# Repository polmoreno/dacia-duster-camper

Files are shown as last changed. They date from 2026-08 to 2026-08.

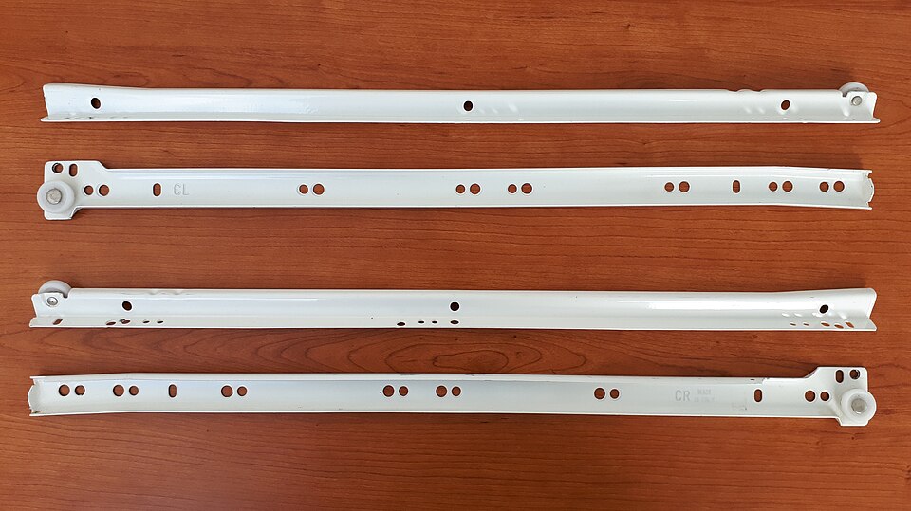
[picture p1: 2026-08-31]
docs/site/img/ref/drawer-slide.jpg

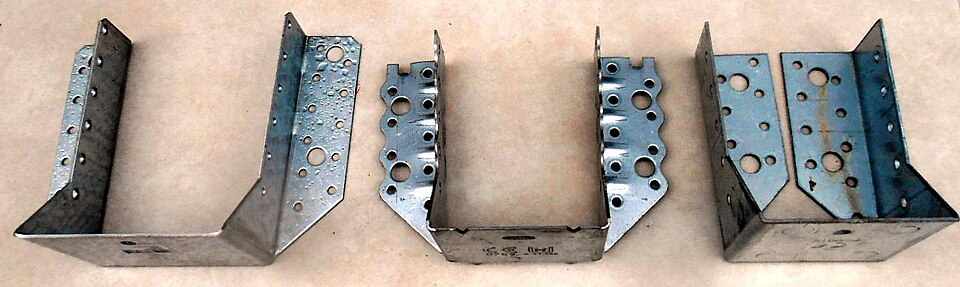
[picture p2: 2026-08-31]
docs/site/img/ref/joist-hanger.jpg

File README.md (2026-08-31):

# Duster II Sleep Pack clone

DIY plans for a **Dacia Duster II (2018–2024) 1.6 GLP 115 Ambiance 4x2** clone of the official InNature Sleep Pack.

The factory SKU ([7717274284](https://www.dacia.es/accesorios-dacia/catalogo/detalles.html?productId=PA_7717274284)) is a **Duster III** part. It will not drop into this car. The **sleep size** does: **1900 × 950 mm** between the wheel arches, **1300 mm** at the rear doors via slide-out wings.

3-in-1 only: removable boot box, storage while the bed is open, rear picnic table (15 kg). No kitchen. No drilling.

## Quick start

0. Open the workshop site (English / Catalan): [docs/site/](docs/site/index.html) — parts, tape-measure fit, shopping list, 3D, build steps.
1. Print and fill [docs/vehicle.md](docs/vehicle.md) in the car.
2. If your numbers differ from v0.1, edit [cad/params.py](cad/params.py) and run `python cad/export_cnc.py`.
3. Plot [cad/export/cardboard-templates.svg](cad/export/cardboard-templates.svg) at 100% and tape it in the Duster.
4. Cut two 2440 × 1220 × 15 mm sheets from [cad/export/sheet-1.svg](cad/export/sheet-1.svg) / [sheet-2.svg](cad/export/sheet-2.svg) (DXF next to them).
5. Build and deploy with [docs/build-guide.md](docs/build-guide.md). Hardware: [hardware/bom.md](hardware/bom.md).
6. Watch the 3D assemble / fold / sleep animation in [docs/viewer/](docs/viewer/index.html).

## Repo map

| Path | What |
| --- | --- |
| [docs/site/](docs/site/index.html) | Interactive workshop site (EN / CA) for the hardware-store counter |
| [docs/research.md](docs/research.md) | Official pack vs Duster II, sources, why 190×130 is still the target |
| [docs/vehicle.md](docs/vehicle.md) | Published dims + tape-measure checklist (including 130 cm wings) |
| [docs/build-guide.md](docs/build-guide.md) | Cut, assemble, strap, official 9-step unfold, safety |
| [docs/drawings/](docs/drawings/) | Folded, unfolded, exploded SVG |
| [docs/viewer/](docs/viewer/index.html) | 3D animation: kit → folded box → picnic / sleep |
| [cad/params.py](cad/params.py) | All millimetre variables |
| [cad/sleep_pack.scad](cad/sleep_pack.scad) | OpenSCAD preview (`unfolded = true`) |
| [cad/export/](cad/export/) | Nested SVG + DXF, cut list, cardboard templates |
| [hardware/bom.md](hardware/bom.md) | Wood, hinges, straps, foam |

## v0.1 numbers (change after measuring)

| | mm |
| --- | --- |
| Box outer | 950 × 800 × 320 |
| Bed | 1900 × 950 |
| Wings | 175 each → **1300** at the doors |
| Plywood | 15 mm, 2 sheets, 4.23 m² net |

Typical DIY cost **€200–380** vs ~€1,590 official.

Python 3.10+ is enough to regenerate files (`python cad/export_cnc.py`). No extra packages.

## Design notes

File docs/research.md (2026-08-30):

# Research: Duster II Sleep Pack clone

Original design notes. This project clones the **public function** of Dacia’s InNature Sleep Pack for a **Duster II (2018–2024) 1.6 GLP 115 Ambiance 4x2**. It does not copy official CNC outlines or paid DIY PDFs.

## Official SKU vs this car

| Item | Official pack | This project |
| --- | --- | --- |
| SKU | [7717274284](https://www.dacia.es/accesorios-dacia/catalogo/detalles.html?productId=PA_7717274284) (Spain) | Original Duster II geometry |
| Title on dacia.es | Pack Sleep for Duster 4x2 and **Hybrid 150 4x4 without spare** | — |
| Fitment | Duster III (2024+), plus separate SKUs for Jogger / Bigster | Duster II 4x2 GLP |
| Box width | Built for **1000 mm** between wheel arches | Built for **977 mm** (target outer width 950 mm) |
| Sleep size | 190 × 130 cm mattress (100 cm in the boot, 130 cm at the rear doors) | Same sleep size, Duster II envelope |
| Weight | ~45 kg box + 5 kg mattress | Target ≤ 45 kg box |
| Price | ~€1,590–1,650 | DIY wood + hardware ~€200–400 |
| Designer | Eric Bouffette / Qstomize (Renault Group) | This repo |

Hybrid 150 4x4 exists only on Duster III. The 1.6 SCe 115 LPG (GLP) and Ambiance trim are Duster II. Dacia NL states each model has its **own** Sleep Pack because the interiors differ.

The dacia.es “modelos disponibles” list that includes Sandero, Logan, Dokker, Lodgy, Spring, and “DUSTER 1 PHAS2” is a catalogue dump, not a fitment check. It does not list Duster II.

**The official box will not drop into a Duster II boot.** The official *sleep size* is still the target.

### Published cargo comparison

| Dimension | Duster III (official pack car) | Duster II 4x2 (this car) |
| --- | --- | --- |
| Width between wheel arches | 1000 mm | **977 mm** |
| Load length, seats up | ~665–990 mm (generation-specific) | **990 mm** |
| Load length, seats folded | 1672 mm | **1792 mm** (longer) |
| Rear elbow / shoulder | ~1433 / 1377 mm | **1416 / 1379 mm** |
| Boot volume 4x2 | ~472 L | **445 L** |
| Spare / LPG | Hybrid / no-spare variants | LPG tank in the spare-wheel well, typically no spare |

Sources: Duster II press kit ([RE37517](https://www.press.dacia.co.uk/assets/documents/original/3064-RE37517DaciaDusterPressKitV1.pdf)); Duster III dimensions (Autotijd / Dacia).

The official 190 × 130 cm figure is the **unfolded mattress**, not the box. Motorpasión quotes the Duster III box at about **1000 × 800 × 300 mm**. Reviews (Motor1) give the bed as **190 cm long, 100 cm in the boot, 130 cm at the rear doors**.

## Official unfold (public reviews)

Compiled from Autofácil, Auto Express, and Motor1. No official exploded drawing is public.

1. Push the front seats fully forward (cushion and backrest).
2. Fold the rear seats.
3. Remove the two wooden cross-slats stored on the box (used later).
4. Release the retaining strap and pull the **concertina / hinged frame** out over the folded seatbacks.
5. Slot the two cross-slats across the frame (width-ways braces).
6. Unfold the **Z-fold three-section deck** so it rests on the box and the frame.
7. Slide out the **side wings** to use the space up to the rear door glass (~130 cm at the shoulders).
8. Unfold the foam mattress (stored between the parcel shelf and the box) and add the two wing pads.
9. Add side / footwell cushions so nobody rolls into the front footwell.

Other official traits used here:

- Rear flap of the box folds down as a picnic table (**15 kg max**; do not sit on it).
- Storage stays reachable with the bed open (~160–175 L on Duster III; this clone targets a similar cavity).
- Box straps to factory boot tie-downs. No drilling.
- Mattress: 100% polyester foam, **32 kg/m³** (Motor1).
- Two-adult rating on aftermarket listings: **180 kg** total.

Early prototypes used fold-out flaps for the extra width; the production pack uses **slide-out** wings (Auto Express).

## Commercial and DIY sources (not copied)

None of these publish free complete cut lists for a Sleep Pack clone. Geometry in this repo is original.

| Source | What it is | Sleep size | Notes |
| --- | --- | --- | --- |
| [Kit Mueble Camper](https://www.kitmueblecamper.com/dacia-duster/) | Paid furniture kit, kitchen + chest | ~180 × 110 cm | 15 mm plywood, ~30–35 kg poplar, from ~€600. 2017–2023 is workshop adaptation. |
| [Simple Campervans MK2](https://www.simplecampervans.com/shop/conversion-modules/dacia-duster-camper-van-conversion/) | Paid CNC module | 1730 × 900 mm (cushions 1800 × 1000) | 12 mm birch, 21 kg, £399. No kitchen. |
| [Campal Estate](https://campal.co.uk/campal-estate/) | Paid kitchen + bed kit | Vehicle-specific | £1,320–1,520. Separate small/extendable variant for Duster 4x4 / bi-fuel / spare. |
| [Tchao Tchao](https://tchao-tchao.com/es/pages/kit-amenagement-duster) | Paid Duster kit | 190 × 122 cm | Two drawers, adjustable legs. |
| [mobiles-bett.de](https://mobiles-bett.de/en/dacia-duster-en/) | Paid €9.95 instructions | 1950 × 1100 mm | Square timber + fibreboard platform, not a 3-in-1 box. |
| [Etsy camping-box PDF](https://www.etsy.com/listing/1596598387/wooden-camping-box-project-foldable-bed) | Paid tutorial | 164 × 98 cm deck | Written for Duster II 1.0 TCe LPG 4x2 Access. |
| [Reddit Duster 2 bed](https://www.reddit.com/r/Dacia/comments/1sq65s0/diy_bed_frame_for_the_duster_2/) | Photos | — | No published plans. |
| [Foro Dacia kit thread](https://www.foroclub.es/duster/viewtopic.php?t=6945) | Forum | — | Author promised plans; they were not posted. |
| [Nimblecamper DIY](https://nimblecamper.com/dacia-duster-camper-diy/) | Photo example | ~176 cm boot, 180+ cm with front seats forward | Push front seats forward for length. |

Third-party Duster II kits usually skip the official **wings**, which is why they advertise ~180 × 110 cm. This clone keeps the wings so the sleep surface matches the official 190 × 100 / 130 cm.

## Design decisions

1. **Sleep size matches the official pack:** 1900 mm long, 1000 mm between the arches, 1300 mm at the rear doors via slide-out wings.
2. **Box is narrower than the official pack:** 950 mm outer width (977 mm arches minus clearance).
3. **No kitchen drawer.** 3-in-1 only: storage + table + bed.
4. **Parametric CAD.** Published Duster II numbers are v0.1. Measure the car, then regenerate cuts (see [vehicle.md](vehicle.md)).
5. **15 mm birch or phenolic plywood.** Official pack is hygienic birch. Butt joints, glue, screws, corner brackets — no hidden dados required.
6. **Quita-y-pon.** Strapped cargo, not a homologated conversion.

## Sources

- [dacia.es SKU 7717274284](https://www.dacia.es/accesorios-dacia/catalogo/detalles.html?productId=PA_7717274284)
- [dacia.co.uk InNature](https://www.dacia.co.uk/innature-accessories.html)
- [dacia.nl Sleep Pack (per-model sizes)](https://www.dacia.nl/accessoires/sleep-pack.html)
- [Autofácil: nine-step Jogger/Duster unfold](https://www.autofacil.es/video-dacia-pack-sleep/)
- [Auto Express: prototype, slats, wings](https://www.autoexpress.co.uk/dacia/359729/dacia-jogger-sleep-pack-exclusive-review-night-amazing-budget-motorhome)
- [Motor1 Duster Sleep Pack test (190 / 100 / 130, 45+5 kg, 32 kg/m³)](https://www.motor1.com/reviews/723549/dacia-duster-sleep-pack-first-drive-review/)
- [Autocar Duster overnight](https://www.autocar.co.uk/car-news/features/future-camping-we-spend-night-dacias-%C2%A32000-sleep-pack)
- [Motorpasión box envelope ~1000 × 800 × 300 mm](https://www.motorpasion.com/furgonetas-y-caravanas/me-he-configurado-dacia-duster-sea-camper-24-000-euros-ahora-tengo-coche-casa-ruedas-para-finde)
- [Autobild: Duster III only](https://www.autobild.es/motor/dacia-duster-puede-convertirse-camper-con-dacia-pack-sleep-una-caja-con-que-se-puede-hacer-magia_6929495_0.html)

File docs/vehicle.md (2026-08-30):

# Duster II 4x2 GLP — vehicle pack and measure checklist

Print this page. Fill the **Measured** column in millimetres before cutting 15 mm plywood.

Car: **Dacia Duster II (2018–2024) 1.6 GLP 115 Ambiance 4x2**

GLP (LPG) tanks sit in the spare-wheel well. Expect a repair kit, not a spare, and a relatively flat boot floor compared with a 4x4 that carries a spare.

## Published starting dimensions (v0.1 CAD)

From the Duster II press kit unless noted. These are the defaults in `cad/params.py`.

| ID | What | Published | v0.1 CAD | Measured |
| --- | --- | --- | --- | --- |
| A | Width between wheel arches (narrowest) | 977 mm | box outer **950 mm** | |
| B | Load length, rear seats **up**, floor to seatback | 990 mm | box depth **800 mm** | |
| C | Load length, rear seats **folded**, floor to front-seat back | 1792 mm | bed length **1900 mm** (front seats fully forward) | |
| D | Rear elbow width | 1416 mm | — | |
| E | Rear shoulder width | 1379 mm | wings to **1300 mm** | |
| F | Boot volume 4x2 | 445 L | — | |
| G | Parcel-shelf height above boot floor | not published | box height **320 mm** | |
| H | Wheelbase | 2674 mm | — | |

Duster III (official pack car) is **1000 mm** between arches and **1672 mm** seats-folded. Do not use those numbers for cuts.

## How to measure

Use a steel tape. Two people helps for C and W1. Record the **smallest** number if the gap tapers.

Set-up for sleep-mode measurements (C, G, S1–S3, W1–W3, L1):

1. Front seats fully forward, backrests upright or slightly reclined as you would sleep.
2. Rear headrests removed or pushed down.
3. Rear seatbacks folded toward the front.
4. Parcel shelf removed.

Set-up for daily-mode measurements (A, B, G, T1–T4):

1. Rear seats up, usable for passengers.
2. Parcel shelf in its normal position.

## Print-ready checklist

### Boot envelope (box must fit)

| ID | Measure | How | Target / limit | Measured mm | OK? |
| --- | --- | --- | --- | --- | --- |
| A | Arch width | Narrowest gap between wheel-arch plastics, 50 mm above the floor | ≥ 960 (950 box + 10 clearance) | | |
| A2 | Arch width at 200 mm | Same gap at 200 mm above the floor (arches often lean in) | ≥ 960 | | |
| A3 | Arch width at shelf | Same gap at parcel-shelf height | ≥ 960 | | |
| B | Depth seats up | Inner tailgate plastic to rear seatback, on the floor centreline | ≥ 820 (800 box + 20) | | |
| B2 | Depth at mid height | Same, at 160 mm above the floor | ≥ 820 | | |
| G | Shelf height | Boot floor to underside of parcel shelf, centre | ≥ 330 (320 box + 10) | | |
| G2 | Floor flatness | Highest bump vs lowest point of the boot floor (GLP well / foam floor) | note mm | | |
| T1–T4 | Tie-downs | X/Y of each factory loop from the left-front corner of the boot floor | strap reach | | |

### Sleep envelope (bed 190 × 100 / 130)

| ID | Measure | How | Target / limit | Measured mm | OK? |
| --- | --- | --- | --- | --- | --- |
| C | Length seats folded | Inner tailgate to the back of the front seats (seats fully forward) | ≥ 1900 | | |
| C2 | Length to dash / pedals | If C < 1900, can feet go between the front seats? Note extra mm | 1900 − C | | |
| L1 | Deck height check | Folded seatback height above boot floor (highest point of the 60/40 split) | compare to 320 | | |
| S1 | Seatback angle | Angle of the folded backrest from horizontal (phone inclinometer) | typical 10–25° | | |
| S2 | Seatback contact Y | Distance from inner tailgate to the first point the frame will rest on the seatback | | | |
| S3 | Front footwell drop | Floor height in the rear footwell vs boot floor (for front legs) | | | |
| W1 | Door-area width | Inside-to-inside at **mattress height** (~320 mm) between rear door cards / plastics, with doors closed | ≥ 1320 (1300 + 20) | | |
| W2 | Door-area width at head | Same, 200 mm above the deck (shoulder room) | ≥ 1320 | | |
| W3 | Wing length available | Along Y, how long a 150 mm-wide wing can sit without hitting the C-pillar or arch | ≥ 600 | | |

### Hardware

| ID | Measure | How | Measured |
| --- | --- | --- | --- |
| H1 | Tie-down type | Photo + loop ID size (mm) | |
| H2 | 60/40 split | Both sides fold? Height mismatch left vs right (mm) | |
| H3 | Parcel shelf keep? | Can the shelf sit above a 320 mm box? yes/no | |
| H4 | Year / VIN year | Plate or V5 | |

## Sketch — where to put the tape

```text
TOP VIEW (rear seats folded, looking down)

        FRONT SEATS (pushed forward)
   +----------- C / C2 ----------------+
   |                                   |
   |     W1 / W2 (door-area width)     |
   |   <-------- 1300 target --------> |
   |         [wing]     [wing]         |
   |                                   |
   |  A = arch width (977 published)   |
   |   <-------- 950 box -------->     |
   |                                   |
 TAILGATE                         TAILGATE
   +------------- B (seats up) --------+

SIDE VIEW

  roof
   |        parcel shelf ---- G
   |   +--------+
   |   |  BOX   | 320          folded seatback / S1
   |   | 800 mm |==============\\======== deck 1900
   |   +--------+              legs
   +---- boot floor / G2 --+  footwell S3
         T1  T2     T3  T4
```

## After measuring

1. Edit the matching variables in [`cad/params.py`](../cad/params.py) (`BOOT_ARCH_WIDTH`, `BOX_WIDTH`, `BOX_DEPTH`, `BOX_HEIGHT`, `BED_LENGTH`, `WING_EXTRA`, `SEATBACK_ANGLE_DEG`, …).
2. Run `python cad/export_cnc.py` to regenerate SVG, DXF, nests, and drawings.
3. Cut the **cardboard templates** first ([`cad/export/cardboard-templates.svg`](../cad/export/cardboard-templates.svg)). Tape them in the car.
4. Only then cut 15 mm plywood.

If A, A2, or A3 is under 960 mm, shrink `BOX_WIDTH` to measured − 20 mm. If W1 is under 1320 mm, shrink `WING_EXTRA` so `BED_WIDTH + 2*WING_EXTRA` ≤ W1 − 20. If C is under 1900 mm, either accept a shorter bed or plan to put feet between the front seats and shorten `BED_LENGTH` to what actually lies flat.

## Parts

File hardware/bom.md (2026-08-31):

# Bill of materials — Duster II Sleep Pack clone v0.1

Prices are Spain hardware-store ballparks. Preferred shop: **[Cadena 88](https://www.cadena88.com/es)** (pick a store by postcode; web prices are recommended PVP, stock is local). Buy after the cardboard templates fit.

Cadena 88 web matches (Aug 2026):

| Need | Cadena 88 product | Link |
| --- | --- | --- |
| Edge band 22 mm | Canto melamina EHL 5 m × 22 mm, SKU 111D2283 (~4,60 €) | [producte](https://www.cadena88.com/es/ferreteria/ferreteria-para-muebles/cantos-para-tablero/canto-melamina-ehl-5-m-x-22-mm) |
| Piano hinge | Bisagra piano niquelada EHL 32 × 1020 mm, SKU 111D383 (~4,10 €) | [producte](https://www.cadena88.com/es/cerrajeria/accesorios-puertas-y-ventanas/bisagras-y-pernios/bisagras-de-piano/bisagra-piano-niquelada-ehl-en-tiras) |
| Leg hinges | Bisagra EHL 207, pack de 4, 40 × 35 mm, SKU 111D315 (~4,40 €) | [producte](https://www.cadena88.com/es/cerrajeria/accesorios-puertas-y-ventanas/bisagras-y-pernios/bisagras/bisagra-ehl-modelo-207) |
| Table bolts | Pasador cerrojo EHL bicromatado 70 mm, SKU 111D313 (~4,15 €) | [producte](https://www.cadena88.com/es/cerrajeria/pasadores-candados-y-cierrapuertas/pasadores-y-pestillos-para-puertas/pasadores-y-pestillos/pasador-cerrojo-ehl-bicromatado) |
| Wing runners | Guía metálica EUROLATON **500 mm** (~4,50 € / pair, 45 kg) | [producte](https://www.cadena88.com/es/ferreteria/ferreteria-para-muebles/complementos-para-muebles/guia-metalica-eurolaton-cajones) |
| Corner brackets | Escuadras EHL punta redonda 40 × 40 mm, SKU 111D12-26 (from ~2,00 €) | [producte](https://www.cadena88.com/es/ferreteria/ferreteria-para-muebles/pletinas-y-escuadras-de-ensamblaje/escuadras-ehl-punta-redonda-bricomatadas) |
| Glue | Cola blanca rápida CEYS 500 g, SKU 4572B59 (~6,60 €) | [producte](https://www.cadena88.com/es/fijaciones-y-adhesivos/adhesivos-colas-y-cintas/colas-blancas/adhesivo-cola-blanca-rapida-ceys-500-gr) |
| Screws | SPAX CP Wirox chipboard — pick 4×40 and 3.5×20 on the same page | [producte](https://www.cadena88.com/es/fijaciones-y-adhesivos/tornillos-tacos-y-clavos/tornillos-y-tirafondos/tornillos-rosca-madera/tornillo-aglomerado-spax-cp-wirox-z2-tr) |

**Ask at the shop (not on the website):** 15 mm birch/phenolic 2440 × 1220, pine 20×20 cleat, felt pads, table stays, cam-buckle straps, foam mattress. Do not buy the Emuca 30 mm table tops.

## Plywood

| Item | Spec | Qty | Notes | Est. € |
| --- | --- | --- | --- | --- |
| Birch or phenolic plywood | 2440 × 1220 × **15 mm** | **2 sheets** | Nested in [`cad/export/sheet-1.svg`](../cad/export/sheet-1.svg) and `sheet-2`. Poplar is lighter; HPL phenolic is toughest. | 80–140 |
| Edge banding | 22 mm iron-on, matching | 20 m | All cut edges that you will touch | 10 |
| Felt / wool pads | 3 mm, self-adhesive | 1 pack | Under the box and on seat-rest blocks | 6 |

Cut list: [`cad/export/cutlist.csv`](../cad/export/cutlist.csv) and [`cad/export/parts.md`](../cad/export/parts.md). Net area 4.23 m²; two sheets are 5.95 m².

Optional instead of plywood slat sockets: four steel 40 × 40 × 80 mm U-brackets.  
Optional instead of plywood `WING_RUNNER` strips: two pairs of 550 mm drawer slides under P2.

## Timber (not CNC)

| Item | Spec | Qty | Use | Est. € |
| --- | --- | --- | --- | --- |
| Pine cleat | 20 × 20 mm | 3 m | Bottom sits on cleats glued to SIDE_L/R, FRONT, RAIL_BOT | 6 |

## Hinges and stays

| Item | Spec | Qty | Use | Est. € |
| --- | --- | --- | --- | --- |
| Piano hinge | 32 × 950 mm, steel or stainless | 2 | DECK_P1–P2 and P2–P3 | 16 |
| Piano hinge | 32 × 920 mm | 2 | TABLE to RAIL_TOP; P1 to RAIL_TOP | 16 |
| Piano hinge | 32 × 80 mm (or 2× 40 mm butt) | 4 | RAIL_SEG A–B (two per side) | 8 |
| Butt hinge | 40 mm | 4 | LEG to RAIL_SEG B (two per leg) | 4 |
| Folding table stay | 200–250 mm, 15 kg rated | 2 | TABLE underside to SIDE_L/R | 10 |
| Barrel bolts | 50 mm | 2 | Hold TABLE closed while driving | 4 |

## Fasteners

| Item | Spec | Qty | Use | Est. € |
| --- | --- | --- | --- | --- |
| Wood screws | 4 × 40 mm | 100 | Box carcass | 6 |
| Wood screws | 3.5 × 20 mm | 80 | Hinges, runners, sockets | 4 |
| Corner brackets | 40 × 40 × 40 mm | 8 | Inside box corners | 6 |
| PVA / PU wood glue | D3/D4 | 1 bottle | All butt joints | 8 |
| Threaded inserts + M6 | optional | 8 | If you want a take-apart box | 8 |

## Straps and comfort

| Item | Spec | Qty | Use | Est. € |
| --- | --- | --- | --- | --- |
| Cam-buckle lashing strap | 25 mm × 2 m | 4 | Through SIDE slots to factory tie-downs | 16 |
| Soft loop / webbing | 25 mm | 2 m | Protect the tie-down plastics | 4 |
| Foam mattress | 50 mm, 32 kg/m³ polyester (official spec) or 80 mm PU | 1 | 950 × 1900 mm main | 40–80 |
| Wing pads | same foam | 2 | 175 × 549 mm | included if cut from leftover |
| Footwell pads | 80 mm foam | 2 | 150 × 400 mm | 15 |
| Mattress covers | zip, washable | 3 | Main + two wings | 20 |

80 mm foam is more comfortable than the official 50 mm / 32 kg/m³ slab. If you use 80 mm, confirm parcel-shelf height (measure G) still clears the folded stack.

## Tools

Circular saw or CNC/panel saw, 2 mm drill, countersink, square, clamps, iron (edge band), 2 mm hex / Pozidriv. A hardware store will cut the nest if you take printed [`sheet-1.svg`](../cad/export/sheet-1.svg) / [`sheet-2.svg`](../cad/export/sheet-2.svg) or the DXF files.

## Total

| | € |
| --- | --- |
| Wood + glue + band | 100–160 |
| Hardware | 70–100 |
| Foam + covers | 75–120 |
| **Typical DIY** | **€200–380** |

Official Sleep Pack: ~€1,590. Kit Mueble Camper (different layout): from ~€600.

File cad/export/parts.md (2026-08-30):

# CNC parts — v0.1

Plywood area (no waste): **4.23 m²**.
Sheets: **2440 × 1220 × 15 mm**.

| Part | Qty | W mm | H mm | Group | Notes |
| --- | --- | --- | --- | --- | --- |
| `SIDE_L` | 1 | 800 | 320 | box | Left side. Four strap slots to factory tie-downs. |
| `SIDE_R` | 1 | 800 | 320 | box | Right side. Same as SIDE_L (box is symmetric). |
| `BOTTOM` | 1 | 920 | 770 | box | Sits between the sides. Glue and screw into 20x20 cleats. |
| `FRONT` | 1 | 920 | 305 | box | Cabin-facing wall. Top edge is the landing for deck P1. |
| `RAIL_TOP` | 1 | 920 | 70 | box | Tailgate-end top rail. Piano hinge for TABLE and for P1. |
| `RAIL_BOT` | 1 | 920 | 50 | box | Tailgate-end bottom rail. Closes the storage opening. |
| `TABLE` | 1 | 918 | 198 | box | Picnic flap, 15 kg max. Finger slot. Two folding stays. |
| `DECK_P1` | 1 | 950 | 800 | deck | Box lid / first deck section. Hinge to RAIL_TOP. |
| `DECK_P2` | 1 | 950 | 549 | deck | Middle section (rear-door bay). Wing tracks on the underside. |
| `DECK_P3` | 1 | 950 | 549 | deck | Front section (toward the front seats). |
| `WING` | 2 | 175 | 549 | deck | Slide-out shoulder wings. One left, one right, under P2. |
| `WING_RUNNER` | 4 | 549 | 20 | deck | Pair of 20 mm guides per wing, screwed under P2. |
| `RAIL_SEG` | 4 | 550 | 80 | frame | Two hinged segments per side. Piano hinge between A/B. |
| `SLAT` | 2 | 918 | 80 | frame | Width-ways braces. Drop into U-sockets on the rails. |
| `LEG` | 2 | 80 | 305 | frame | Folding front legs. Hinge to the free end of RAIL_SEG B. |
| `SEAT_REST` | 2 | 80 | 50 | frame | Short blocks under the rails where they meet the seatbacks. |
| `SLAT_SOCKET` | 4 | 40 | 90 | frame | U-shaped catch. Screw to the inside of the rails. Or use steel U-brackets. |

## Locked parameters

| Name | mm |
| --- | --- |
| `BOX_WIDTH` | 950 |
| `BOX_DEPTH` | 800 |
| `BOX_HEIGHT` | 320 |
| `INNER_W` | 920 |
| `INNER_D` | 770 |
| `INNER_H` | 305 |
| `BED_LENGTH` | 1900 |
| `BED_WIDTH` | 950 |
| `WING_TOTAL` | 1300 |
| `WING_EXTRA` | 175 |
| `P1_LEN` | 800 |
| `P2_LEN` | 549 |
| `P3_LEN` | 549 |
| `FRAME_LEN` | 1100 |
| `TABLE_W` | 918 |
| `TABLE_H` | 198 |
| `PLY` | 15 |

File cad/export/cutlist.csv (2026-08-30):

name | qty | width_mm | height_mm | thickness_mm | group | notes
SIDE_L | 1 | 800.0 | 320.0 | 15 | box | Left side. Four strap slots to factory tie-downs.
SIDE_R | 1 | 800.0 | 320.0 | 15 | box | Right side. Same as SIDE_L (box is symmetric).
BOTTOM | 1 | 920.0 | 770.0 | 15 | box | Sits between the sides. Glue and screw into 20x20 cleats.
FRONT | 1 | 920.0 | 305.0 | 15 | box | Cabin-facing wall. Top edge is the landing for deck P1.
RAIL_TOP | 1 | 920.0 | 70.0 | 15 | box | Tailgate-end top rail. Piano hinge for TABLE and for P1.
RAIL_BOT | 1 | 920.0 | 50.0 | 15 | box | Tailgate-end bottom rail. Closes the storage opening.
TABLE | 1 | 918.0 | 198.0 | 15 | box | Picnic flap; 15 kg max. Finger slot. Two folding stays.
DECK_P1 | 1 | 950.0 | 800.0 | 15 | deck | Box lid / first deck section. Hinge to RAIL_TOP.
DECK_P2 | 1 | 950.0 | 549.0 | 15 | deck | Middle section (rear-door bay). Wing tracks on the underside.
DECK_P3 | 1 | 950.0 | 549.0 | 15 | deck | Front section (toward the front seats).
WING | 2 | 175.0 | 549.0 | 15 | deck | Slide-out shoulder wings. One left; one right; under P2.
WING_RUNNER | 4 | 549.0 | 20.0 | 15 | deck | Pair of 20 mm guides per wing; screwed under P2.
RAIL_SEG | 4 | 550.0 | 80.0 | 15 | frame | Two hinged segments per side. Piano hinge between A/B.
SLAT | 2 | 918.0 | 80.0 | 15 | frame | Width-ways braces. Drop into U-sockets on the rails.
LEG | 2 | 80.0 | 305.0 | 15 | frame | Folding front legs. Hinge to the free end of RAIL_SEG B.
SEAT_REST | 2 | 80.0 | 50.0 | 15 | frame | Short blocks under the rails where they meet the seatbacks.
SLAT_SOCKET | 4 | 40.0 | 90.0 | 15 | frame | U-shaped catch. Screw to the inside of the rails. Or use steel U-brackets.

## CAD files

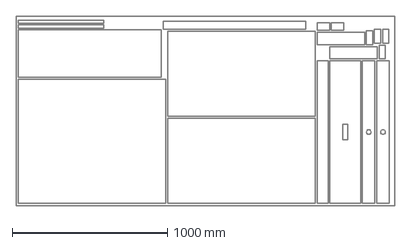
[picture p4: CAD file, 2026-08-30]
cad/export/sheet-1.dxf
2440.0 x 1220.0 mm

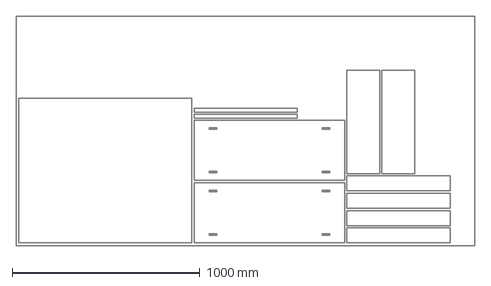
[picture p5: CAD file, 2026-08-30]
cad/export/sheet-2.dxf
2440.0 x 1220.0 mm

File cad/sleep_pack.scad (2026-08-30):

// Duster II Sleep Pack clone — v0.1 visualization
// Open in OpenSCAD. Set unfolded = true to see the bed deployed.
// Numbers match cad/params.py — if you change params.py, update these.

unfolded = false;

ply = 15;
box_w = 950;
box_d = 800;
box_h = 320;
inner_w = box_w - 2 * ply;
inner_d = box_d - 2 * ply;
inner_h = box_h - ply;
rail_top_h = 70;
rail_bot_h = 50;
table_w = inner_w - 2;
table_h = box_h - rail_top_h - rail_bot_h - 2;

p1 = 800;
p2 = 549;
p3 = 549;
deck_gap = 2;
bed_w = 950;
wing = 175;
wing_len = p2;
frame_rail_h = 80;
leg_h = inner_h;

module ply_xy(w, d) {
    cube([w, d, ply]);
}

module box() {
    // sides
    cube([ply, box_d, box_h]);
    translate([box_w - ply, 0, 0]) cube([ply, box_d, box_h]);
    // bottom
    translate([ply, ply, 0]) cube([inner_w, inner_d, ply]);
    // front (cabin)
    translate([ply, box_d - ply, ply]) cube([inner_w, ply, inner_h]);
    // rear rails
    translate([ply, 0, box_h - rail_top_h]) cube([inner_w, ply, rail_top_h]);
    translate([ply, 0, 0]) cube([inner_w, ply, rail_bot_h]);
}

module table_flap() {
    color("#c9b48a")
    translate([ply + 1, -table_h, rail_bot_h + 1])
        cube([table_w, ply, table_h]);
}

module deck_folded() {
    color("#c9b48a") {
        translate([0, 0, box_h]) ply_xy(bed_w, p1);
        translate([0, 0, box_h + ply]) ply_xy(bed_w, p2);
        translate([0, 0, box_h + 2 * ply]) ply_xy(bed_w, p3);
    }
}

module deck_open() {
    color("#c9b48a") {
        translate([0, 0, box_h]) ply_xy(bed_w, p1);
        translate([0, p1 + deck_gap, box_h]) ply_xy(bed_w, p2);
        translate([0, p1 + p2 + 2 * deck_gap, box_h]) ply_xy(bed_w, p3);
    }
    color("#b9d4c0") {
        translate([-wing, p1 + deck_gap, box_h]) ply_xy(wing, wing_len);
        translate([bed_w, p1 + deck_gap, box_h]) ply_xy(wing, wing_len);
    }
}

module frame_open() {
    color("#9aa7b5") {
        translate([ply, box_d, box_h - frame_rail_h])
            cube([ply, p2 + p3, frame_rail_h]);
        translate([box_w - 2 * ply, box_d, box_h - frame_rail_h])
            cube([ply, p2 + p3, frame_rail_h]);
        translate([2 * ply, box_d + 180, box_h - frame_rail_h])
            cube([inner_w - 2 * ply, ply, frame_rail_h]);
        translate([2 * ply, box_d + 180 + 400, box_h - frame_rail_h])
            cube([inner_w - 2 * ply, ply, frame_rail_h]);
        translate([ply, box_d + p2 + p3 - ply, 0])
            cube([ply, ply, leg_h]);
        translate([box_w - 2 * ply, box_d + p2 + p3 - ply, 0])
            cube([ply, ply, leg_h]);
    }
}

box();
if (unfolded) {
    table_flap();
    deck_open();
    frame_open();
} else {
    deck_folded();
}

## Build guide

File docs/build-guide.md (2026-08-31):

# Build and deploy guide — Duster II Sleep Pack clone v0.1

Official-style 3-in-1: boot box + picnic table + 1900 × 950 / 1300 mm winged bed. No kitchen. No drilling the car.

Read [research.md](research.md) and fill [vehicle.md](vehicle.md) before you cut 15 mm sheets.

## Safety

- Strap the box to the **factory boot tie-downs** whenever the car moves. Treat it as cargo (quita-y-pon), not a homologated conversion.
- Picnic table: **15 kg max**. Do not sit on it.
- Sleep load: **180 kg** total (two adults), same as aftermarket listings of the official pack.
- Deck must rest on the box, the two slats, and the front legs. Do not sleep on an unbraced Z-fold.
- Cook outside the car if you bring a stove. This kit has no kitchen. The car is GLP — keep cartridges disconnected in transit.
- Two people to lift the finished box (~30–45 kg).
- Do not block the rear-view if the folded stack sits above the parcel shelf. Measure G.

## 0. Measure, then cardboard

1. Fill the checklist in [vehicle.md](vehicle.md).
2. If any measured limit is tighter than v0.1, edit [`cad/params.py`](../cad/params.py) and run:

   ```text
   python cad/export_cnc.py
   ```

3. Plot [`cad/export/cardboard-templates.svg`](../cad/export/cardboard-templates.svg) at **100%** (1 unit = 1 mm), or grid it onto taped cardboard.
4. Tape the **box footprint** in the boot with the rear seats **up**. It must clear both arches.
5. Fold the rear seats, push the front seats forward, tape the **bed plan** and the **1300 mm width bar** at mattress height in the rear-door opening.
6. Only then cut plywood.

## 1. Cut

- Nest: [`cad/export/sheet-1.svg`](../cad/export/sheet-1.svg) + [`sheet-2.svg`](../cad/export/sheet-2.svg) (also DXF).
- Two 2440 × 1220 × 15 mm sheets.
- Black lines are cuts. Inner rectangles/circles are cut-outs (strap slots, table handle, slat finger holes).
- Label every part on the face that will be hidden.
- Edge-band every edge you will touch.
- Sand strap slots so webbing does not fray.

Part list: [`cad/export/parts.md`](../cad/export/parts.md).

## 2. Box carcass

Orientation: **Y = 0 at the tailgate**, **Y = 800 at the cabin wall**.

1. Glue 20 × 20 cleats on SIDE_L, SIDE_R, FRONT, and RAIL_BOT, 15 mm up from the bottom so BOTTOM sits flush with the lower edge of the sides.
2. Stand SIDE_L and SIDE_R. Screw FRONT between them at the cabin end, sitting on BOTTOM (or on the cabin cleat). `FRONT` is 305 mm tall so its top lands flush with the 320 mm sides and becomes a landing for DECK_P1.
3. Screw RAIL_BOT and RAIL_TOP between the sides at the tailgate. RAIL_TOP’s top is flush with the side tops.
4. Drop in BOTTOM. Glue and screw down into the cleats.
5. Add four 40 mm corner brackets inside.
6. Piano-hinge TABLE to the **lower** edge of RAIL_TOP so the flap hangs as the rear wall, then folds **out** to horizontal. Fit two folding stays to the sides. 15 kg max.
7. Fit two barrel bolts so TABLE cannot drop while driving.
8. Stick felt under the box.

Storage is the inner cavity (920 × 770 × ~290 mm), reachable through the table opening with the bed open.

## 3. Concertina frame

1. Piano-hinge two RAIL_SEG pieces end-to-end (550 + 550 = 1100 mm) for the left rail. Repeat for the right.
2. Screw two SLAT_SOCKET catches on the inside of each assembled rail — one at ~180 mm from the box, one at ~580 mm. Opening faces up so a SLAT drops in.
3. Butt-hinge one LEG to the free end of each rail so the leg folds against the rail for storage.
4. Screw a SEAT_REST block under each rail where it will sit on the folded seatbacks (measure S2). Add felt.
5. Hinge the **box end** of each rail to the inside of FRONT, near the top, so the rails fold **into** the box for driving and pull out over the seats for sleep.

When deployed, the rails run from the cabin face of the box to the front of P3. Slot both SLATs. Legs stand on the rear footwell / floor (measure S3 — shim LEG_H if the floor is lower than the boot).

## 4. Z-fold deck and wings

1. Rest DECK_P1 on the box as the lid (950 × 800). Piano-hinge it to RAIL_TOP along the **tailgate** long edge so it stays captive and the Z-fold opens toward the cabin.
2. Piano-hinge P2 to the cabin edge of P1 (underside knuckle so the fold stacks upward).
3. Piano-hinge P3 to the cabin edge of P2 (alternate knuckle so it Z-folds).
4. Under P2, screw two WING_RUNNER pairs as 20 mm channels, 15.5 mm apart, opening to the left and right. The WING panels slide in those channels.
5. Add a small end-stop screw so each wing cannot fall out, but can be pulled 175 mm.

Folded stack on the box: P1 (lid) + P2 + P3 ≈ 45 mm, plus the mattress if you store it on top.

## 5. Mattress

Cut foam:

| Piece | Size mm | Qty |
| --- | --- | --- |
| Main | 950 × 1900 × 50 (or 80) | 1 |
| Wing pad | 175 × 549 × same | 2 |
| Footwell pad | 150 × 400 × 80 | 2 |

Zip covers. Official spec is 32 kg/m³ polyester; 80 mm PU is more comfortable if shelf height allows.

## 6. Install in the car (folded / daily)

1. Rear seats up. Parcel shelf out.
2. Two people: box into the boot, centred, felt down.
3. Four cam-buckle straps through the SIDE slots to the factory loops. Snug, do not crush the plastics.
4. Stack P2/P3 (if not already hinged on) and the mattress on the box.
5. Parcel shelf back if measure G still clears.
6. Five seats usable.

## 7. Deploy — official nine steps

Same order as Autofácil’s write-up of the factory pack.

1. Push the **front seats** fully forward (cushion and backrest).
2. Fold the **rear seats**. Remove headrests if they fight the fold.
3. Take out the two **SLATs** (store them in the box while driving).
4. Release the frame retaining strap if you fitted one. Pull the **concertina rails** out over the seatbacks. Legs down.
5. Drop the two SLATs into the sockets (width-ways braces). The frame must feel rigid.
6. Unfold the **Z-fold deck** (P1 stays on the box; P2 and P3 go toward the front seats) so it sits on the rails and slats.
7. Slide out the **wings** to 1300 mm at the rear doors.
8. Lay the **main mattress**, then the two **wing pads**.
9. Place the **footwell pads** so nobody rolls into the front footwell.

Picnic table: open the tailgate, unbolt TABLE, fold the stays. **15 kg. Do not sit.**

To pack: reverse 9 → 1. Slats back in the box. Straps tight before you drive.

## 8. Troubleshooting

| Symptom | Fix |
| --- | --- |
| Box rubs the arches | Shrink `BOX_WIDTH` in `params.py` to measured A − 20, regenerate, recut sides/bottom/deck width |
| 1300 mm wings hit the door cards | Shrink `WING_EXTRA` so `BED_WIDTH + 2*WING_EXTRA` ≤ W1 − 20 |
| Bed shorter than 1900 mm flat | Shorten `BED_LENGTH` or put feet between the front seats |
| Deck not level | Change `LEG_H` / `SEAT_REST_H` to match S1–S3 |
| Parcel shelf will not sit | Store the mattress in the box, or lower `BOX_HEIGHT` |
| Rattle | More felt, tighter straps, foam between P2/P3 |

## 3D preview

Open the workshop site [`docs/site/`](site/index.html) (English / Catalan): 3D, tape-measure fit, shopping list, cut list. Full-screen 3D: [`docs/viewer/index.html`](viewer/index.html). Serve the repo if a page is blank: `python -m http.server`.

Open [`cad/sleep_pack.scad`](../cad/sleep_pack.scad) in OpenSCAD. Set `unfolded = true;` to see the bed out.

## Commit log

2026-08-30 Add Duster II Sleep Pack clone plans and CNC cut files.
    Publish a measure-first parametric DIY pack so the official 190x130 bed can be built for a Duster II without the factory accessory.
    [cutlist.csv, sheet-1.dxf, sheet-2.dxf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]
2026-08-31 Add a dimensioned parts sheet and a 3D assemble-to-sleep viewer.
2026-08-31 Add a bilingual workshop site with real cut drawings and a Pages homepage.
2026-08-31 Add product-photo slides next to the cut drawings.
2026-08-31 Show a hardware-store photo beside each cut drawing.
2026-08-31 Use one 15 mm birch photo for every cut part.
2026-08-31 Show steel U-brackets for SLAT_SOCKET.
2026-08-31 Show drawer slides for WING_RUNNER; keep plywood for the boards.
